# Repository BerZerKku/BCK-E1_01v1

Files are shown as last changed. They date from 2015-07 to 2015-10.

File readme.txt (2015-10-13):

БЦК-Е1

Код ПП: 3.140.003
Код ПП в сборе: 2.140.012

Плата не жизнеспособна! Первый вывод микросхемы 82V2084 находится не по той стороне!
Отверстия под  RJ45 меньше необходимых !

Стэк:
18мкм  TOP 
0.36мм e=4.5
35мкм  GND
0.71мм e=4.5
35мкм  PWR
0.36мм e=4.5
18мкм  BOTTOM
Волновое сопротивление для одиночного проводника: 0.50 мм = 60 Ом (Оркад).
Волновое сопротивление для одиночного проводника: 0.25 мм = 78 Ом (Оркад).
Диф. волновое сопротивление двух проводников: 0.25 мм через 0.25 мм = 120 Ом (Оркад).

!!! Возможно нужны резисторы на шины.

Вопросы:
1. Что делать со сбросом MCU? Завести в альтеру или просто подтянуть к питанию?
2. Не нашел примеров схем с 82V2084, надо ли ставить фильтры по питанию? или достаточно конденсаторов?
3. Разобраться с необходимыми подтяжками сигналов.

Замечания:

MISC
1. На двунаправленной шине данных, подключенной к STM стоит только 5-и вольтовая логика, т.к. все входы МК совместимы с 5В.
2. На входные сигналы идущие в ПЛИС стоит 3-х вольтовая логика тоже совместимую с 5В.
3. На BUSR3 вместо диода стоит транзистор.
4. Разъемы для RJ-45 выбраны 20см с контактом на корпус.

MCU
1. Поставлен резистор 220 Ом последовательно с кварцем. В части тестовых плат он есть, на части нет.
2. BOOT0 = "0", загрузка из FLASH. BOOT1 - не используется.
3. PDR_ON = VDD, внутренняя схема сброса включена.
4. VCAP_1(2) - 2.2 мкФ.
5. 4-е конденсатора 0805 2.2 мкФ, вместо двух по 4.7 мкФ. 12-ть конденсаторов 0805 по 0.1 мкФ. Количество и размеры конденсаторов может измениться по ходу разводки. 
6. VBAT, VUSB напрямую к VDD. 
7. VDDA через бусину к VDD, а так же конденсаторы 1.0 и 0.1 мкФ.
8. VREF+ напрямую к VDDA, а также конденсаторы 1.0 и 0.1 мкФ).
9. Кварц подключен через 220 Ом. На части демоплат этот резистор есть, на части нет. Размер 0805, на демо - скорее всего 0603.
10. Выводы JTAG имеют внутреннюю подтяжку и нет необходимости использовать внешние элементы.

E1
1. Последовательно на выходы/выходы E1 стоят нулевые резисторы 0805, чтобы при необходимости заменить на другой номинал.
2. JTAG TRST подключен к земле "For normal signal processing, this pin should be connected to ground".
3. REF подключен к земле через 0805 3кОм 1%. 
4. IC_7, IC_39 посажены на землю, IC_42 в воздухе.

CPLD
1. Ножки пока назначены для вида. Перестановка будет при разводке.
2. Добавил сигнал #DEV_CLR идущий с одной из ножек CPLD на ножку DEV_CLRn как на БЦК.

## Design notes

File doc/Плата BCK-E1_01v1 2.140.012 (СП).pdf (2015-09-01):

№ | Наименование | Корпус | Кол. | Поз. | Примечание
| | | | | 2.140.012

0

Изм | Лист | № докум. | Подп. | Дата
Разраб. | Щеблыкин М.В | | 01.09.15 | Плата BCK-E1_01v1 Спецификация | Лит. «Прософт-Системы» Н.контр. | Лист | Листов
Провер. | Сагалов Д.С. | | 01.09.15 | | | 1 | 4

### ООО

Назаренко А.Н. | 01.09.15
Утв. | Чирков А.Г.
1 | Сборочный чертеж
| 2.140.012 rev.0 | 1

ДЕТАЛИ
3 | Плата печатная
| 3.140.03 BCK-E1_01v1 | 1

ПРОЧИЕ ИЗДЕЛИЯ

5

Кварцевый резонатор KX-3H
16.3840MHz HC-49/S Geyer | LEAD | 1 | ZQ1

Конденсаторы

9 | 0805 NP0 50V 22pF 5% | 0805 | 2 | C66,C67
11 | 0805 X7R 50V 0.1uF 10% | 0805 | 47 | C8-C19,C21-C23,C26-C29,C32-C35, C37,C39-C43,C45-C58,C61,C68-C70
13 | 0805 X7R 50V 1uF 10% | 0805 | 6 | C2,C3,C20,C36,C59,C62
15 | 0805 X7R 50V 2.2uF 10% | 0805 | 7 | C4-C7,C38,C64,C65
17 | 0805 X7R 10V 10uF 10% | 0805 | 1 | C44
19 | 1812 X7R 3000V 1000pF 10% | 1812 | 2 | C60,C63
21 | тант. 10V 68uF 10% B | B | 5 | C1,C24,C25,C30,C31

Микросхемы

25 | 82V2084PF 128TQFP IDT | TQFP128 | 1 | DD6
27 | ADP3339AKCZ-3.3 SOT223-3 AD | SOT223 | 1 | DA1

2.140.012

Лист

Изм | Лист | № докум. | Подп. | Дата
29 | EPM1270T144C4N TQFP144 Altera | TQFP144 | 1 | DD5
31 | SN74ACT245DW SOIC20 TI | SOIC20 | 2 | DD1,DD2
33 | SN74LVC573ADW SOIC20 TI | SOIC20 | 2 | DD3,DD4
35 | SRDA05-4BTG SOIC8 LittleFuse | SOIC8 | 3 | VD24-VD26
37 | STM32F446ZET6 LQFP144 STM | LQFP144 | 1 | DD7
41 | Предохранитель 04611.25ER
Littelfuse | SMT-2 | 8 | F1-F8

Разъемы

45

1-5406299-1 на плату угловой Ethernet RJ45 R/A 8P T/H SLD
Tyco
10 | 2 | X3,X4
47 | DIN 3x32 96MR | DIN96 | 2 | X1,X2
49 | IDC-10M | IDC10 | 1 | X7
51 | PBD-08 | 8 | 1 | X9
53 | PLS-2 | 2 | 2 | X5,X6
55 | PLS-8 | 8 | 2 | X8,X10

Резисторы

59 | 0805 0 | 0805 | 8 | R12-R15,R24-R27
61 | 0805 60.4 1% | 0805 | 4 | R10,R11,R22,R23
63 | 0805 75 5% | 0805 | 12 | R16-R21,R28-R33
65 | 0805 100 5% | 0805 | 1 | R7
67 | 0805 220 5% | 0805 | 1 | R36
69 | 0805 510 5% | 0805 | 1 | R37
71 | 0805 1K 5% | 0805 | 6 | R2-R4,R6,R8,R9
73 | 0805 2.2K 5% | 0805 | 2 | R1,R5

75 | 0805 3.01K 1% | 0805 | 1 | R34
77 | 0805 5.1K 5% | 0805 | 1 | R35
79 | сборка 1206x4 100 5% | SMT-8 | 8 | RN1-RN8
81 | сборка 1206x4 1K 5% | SMT-8 | 1 | RN22
83 | сборка 1206x4 10K 5% | SMT-8 | 15 | RN9-RN21,RN23,RN24

Светодиоды

87 | FYL-5013PURD1C-60 красный
625нм D5мм 2200мКд Foryard | LEAD-2 | 2 | VD1,VD5 | красный
89 | KP-1608SGC Kingbright (level:3) | 0603 | 1 | VD7 | зеленый
91 | L-53GD | LEAD-2 | 3 | VD2,VD3,VD6 | зеленый
93 | L-53SYT Kingbright | LEAD-2 | 1 | VD4 | желтый

Тиристоры

97 | P0080SAMCLRP Littelfuse | DO-214AA | 4 | VD11,VD12,VD19,VD20
99 | P0300SCMCLRP Littelfuse | DO-214AA | 4 | VD8,VD15,VD16,VD23
101 | P1800SCMCLRP Littelfuse | DO-214AA | 8

VD9,VD10,VD13,VD14,VD17,VD18, VD21,VD22

105 | Транзистор IRLML2803 SOT23 IR | SOT23-3 | 1 | VT1
109 | Трансформатор T1094NL Pulse | SOIC16 | 2 | TR1,TR2
113 | Фильтр PE-65857NL Pulse | SOIC8 | 2 | L1,L2
117 | Фильтр ферритовый BLM18HG471SN1
470Ом 200мА 0603 Murata | 0603 | 3 | FB1-FB3

Лист регистрции изменений СП
№ Изм. | № замененных (измененных) страниц | Дата ревизии | Краткое содержание и причина внесения изменений | Примечание
0 | вновь | 01.09.15

Исполнения:

Лист регистрции изменений СБ
№ Изм. | № замененных (измененных) страниц | Дата ревизии | Краткое содержание и причина внесения изменений | Примечание
0 | вновь | 01.09.15

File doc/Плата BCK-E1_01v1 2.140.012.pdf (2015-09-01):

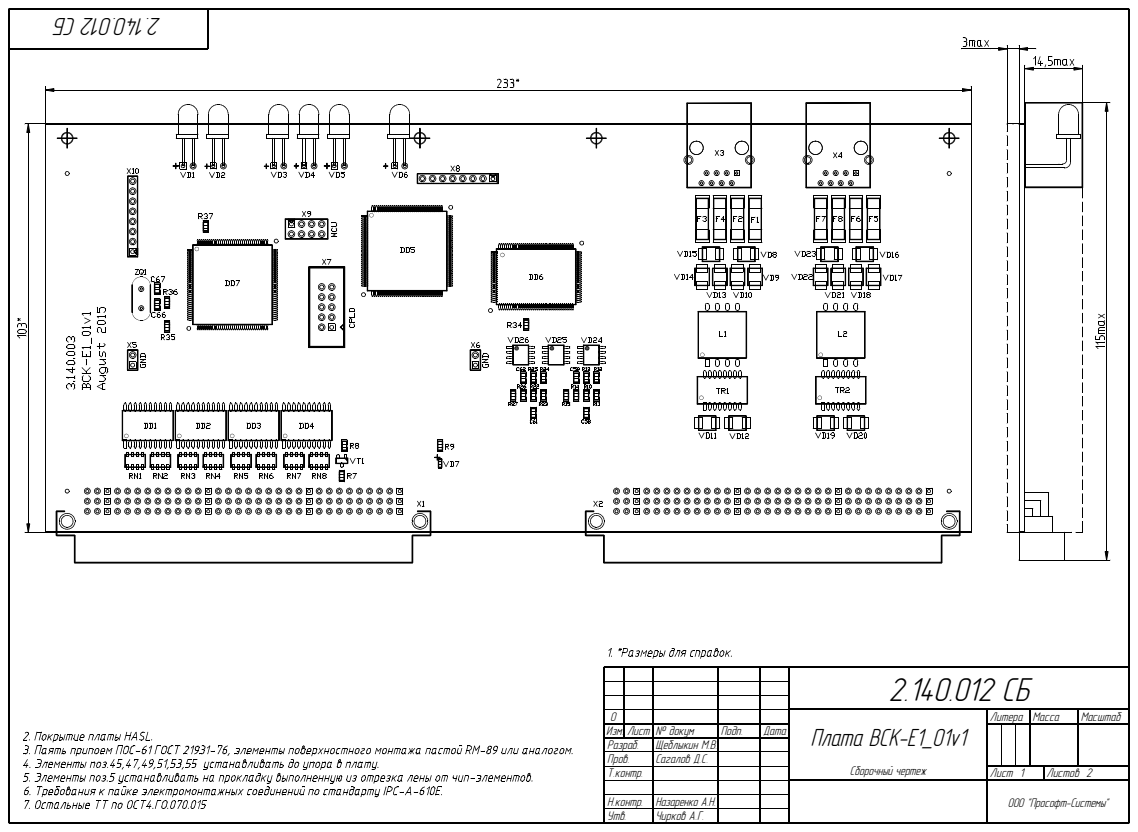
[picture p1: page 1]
Ëèñòîâ 2; Ìàññà; Ìàñøòàá; Ïîäï.; Äàòà; Óòâ.; Í.êîíòð.; Ò.êîíòð.; Ïðîâ.; Ðàçðàá.; Èçì. Ëèñò; ×èðêîâ À.Ã.; Íàçàðåíêî À.Í.; Ñàãàëîâ Ä.Ñ.; Ùåáëûêèí Ì.Â.; № äîêóì; Ëèñò 1; Ëèòåðà; Ïëàòà BCK-E1_01v1

Ñáîðî÷íûé ÷åðòåæ

ÎÎÎ "Ïðîñîôò-Ñèñòåìû"

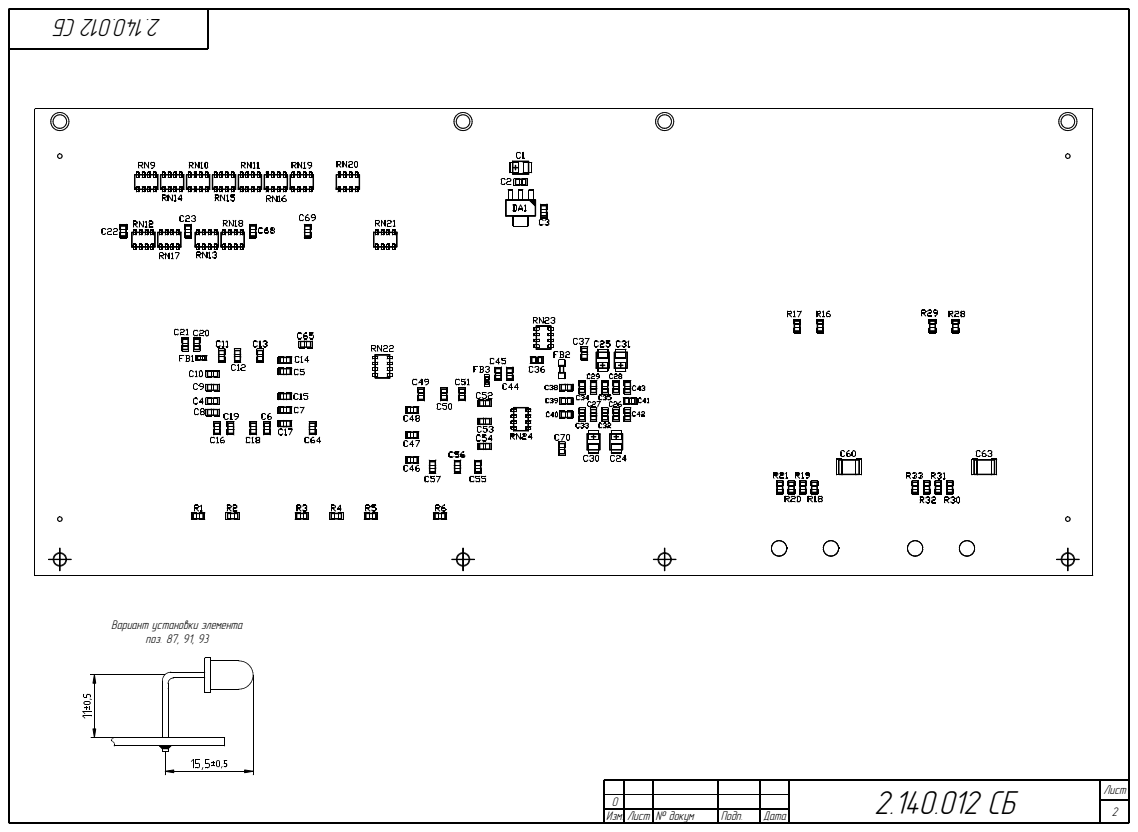
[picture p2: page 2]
Ëèñò; Èçì. Ëèñò № äîêóì; Ïîäï.; Äàòà; ïîç. 87, 91, 93

Âàðèàíò óñòàíîâêè ýëåìåíòà

№ | Наименование | Корпус | Кол. | Поз. | Примечание
| | | | | 2.140.012

0

Изм | Лист | № докум. | Подп. | Дата
Разраб. | Щеблыкин М.В | | 01.09.15 | Плата BCK-E1_01v1 Спецификация | Лит. «Прософт-Системы» Н.контр. | Лист | Листов
Провер. | Сагалов Д.С. | | 01.09.15 | | | 1 | 4

### ООО

Назаренко А.Н. | 01.09.15
Утв. | Чирков А.Г.
1 | Сборочный чертеж
| 2.140.012 rev.0 | 1

ДЕТАЛИ
3 | Плата печатная
| 3.140.03 BCK-E1_01v1 | 1

ПРОЧИЕ ИЗДЕЛИЯ

5

Кварцевый резонатор KX-3H
16.3840MHz HC-49/S Geyer | LEAD | 1 | ZQ1

Конденсаторы

9 | 0805 NP0 50V 22pF 5% | 0805 | 2 | C66,C67
11 | 0805 X7R 50V 0.1uF 10% | 0805 | 47 | C8-C19,C21-C23,C26-C29,C32-C35, C37,C39-C43,C45-C58,C61,C68-C70
13 | 0805 X7R 50V 1uF 10% | 0805 | 6 | C2,C3,C20,C36,C59,C62
15 | 0805 X7R 50V 2.2uF 10% | 0805 | 7 | C4-C7,C38,C64,C65
17 | 0805 X7R 10V 10uF 10% | 0805 | 1 | C44
19 | 1812 X7R 3000V 1000pF 10% | 1812 | 2 | C60,C63
21 | тант. 10V 68uF 10% B | B | 5 | C1,C24,C25,C30,C31

Микросхемы

25 | 82V2084PF 128TQFP IDT | TQFP128 | 1 | DD6
27 | ADP3339AKCZ-3.3 SOT223-3 AD | SOT223 | 1 | DA1

2.140.012

Лист

Изм | Лист | № докум. | Подп. | Дата
29 | EPM1270T144C4N TQFP144 Altera | TQFP144 | 1 | DD5
31 | SN74ACT245DW SOIC20 TI | SOIC20 | 2 | DD1,DD2
33 | SN74LVC573ADW SOIC20 TI | SOIC20 | 2 | DD3,DD4
35 | SRDA05-4BTG SOIC8 LittleFuse | SOIC8 | 3 | VD24-VD26
37 | STM32F446ZET6 LQFP144 STM | LQFP144 | 1 | DD7
41 | Предохранитель 04611.25ER
Littelfuse | SMT-2 | 8 | F1-F8

Разъемы

45

1-5406299-1 на плату угловой Ethernet RJ45 R/A 8P T/H SLD
Tyco
10 | 2 | X3,X4
47 | DIN 3x32 96MR | DIN96 | 2 | X1,X2
49 | IDC-10M | IDC10 | 1 | X7
51 | PBD-08 | 8 | 1 | X9
53 | PLS-2 | 2 | 2 | X5,X6
55 | PLS-8 | 8 | 2 | X8,X10

Резисторы

59 | 0805 0 | 0805 | 8 | R12-R15,R24-R27
61 | 0805 60.4 1% | 0805 | 4 | R10,R11,R22,R23
63 | 0805 75 5% | 0805 | 12 | R16-R21,R28-R33
65 | 0805 100 5% | 0805 | 1 | R7
67 | 0805 220 5% | 0805 | 1 | R36
69 | 0805 510 5% | 0805 | 1 | R37
71 | 0805 1K 5% | 0805 | 6 | R2-R4,R6,R8,R9
73 | 0805 2.2K 5% | 0805 | 2 | R1,R5

75 | 0805 3.01K 1% | 0805 | 1 | R34
77 | 0805 5.1K 5% | 0805 | 1 | R35
79 | сборка 1206x4 100 5% | SMT-8 | 8 | RN1-RN8
81 | сборка 1206x4 1K 5% | SMT-8 | 1 | RN22
83 | сборка 1206x4 10K 5% | SMT-8 | 15 | RN9-RN21,RN23,RN24

Светодиоды

87 | FYL-5013PURD1C-60 красный
625нм D5мм 2200мКд Foryard | LEAD-2 | 2 | VD1,VD5 | красный
89 | KP-1608SGC Kingbright (level:3) | 0603 | 1 | VD7 | зеленый
91 | L-53GD | LEAD-2 | 3 | VD2,VD3,VD6 | зеленый
93 | L-53SYT Kingbright | LEAD-2 | 1 | VD4 | желтый

Тиристоры

97 | P0080SAMCLRP Littelfuse | DO-214AA | 4 | VD11,VD12,VD19,VD20
99 | P0300SCMCLRP Littelfuse | DO-214AA | 4 | VD8,VD15,VD16,VD23
101 | P1800SCMCLRP Littelfuse | DO-214AA | 8

VD9,VD10,VD13,VD14,VD17,VD18, VD21,VD22

105 | Транзистор IRLML2803 SOT23 IR | SOT23-3 | 1 | VT1
109 | Трансформатор T1094NL Pulse | SOIC16 | 2 | TR1,TR2
113 | Фильтр PE-65857NL Pulse | SOIC8 | 2 | L1,L2
117 | Фильтр ферритовый BLM18HG471SN1
470Ом 200мА 0603 Murata | 0603 | 3 | FB1-FB3

Лист регистрции изменений СП
№ Изм. | № замененных (измененных) страниц | Дата ревизии | Краткое содержание и причина внесения изменений | Примечание
0 | вновь | 01.09.15

Исполнения:

Лист регистрции изменений СБ
№ Изм. | № замененных (измененных) страниц | Дата ревизии | Краткое содержание и причина внесения изменений | Примечание
0 | вновь | 01.09.15

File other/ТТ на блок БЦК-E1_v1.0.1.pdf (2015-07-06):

Технические Требования на блок БЦК-E1

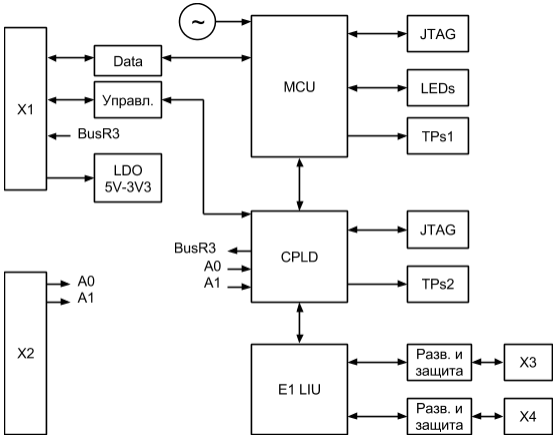
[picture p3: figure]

Общее описание
1. Блоксхема БЦК-E1 представлена на рисунке выше
2. При разработке схемотехники блока БЦК-E1 нужно ориентироваться на схемотехнику блока БЦКО_v2.3 (в той части, которая не описана здесь и которая является общей для обоих блоков)
4. Физические размеры см. БЦКО_v2.3
3. Основное напряжение питания блока 3.3В

Элементная база
1. MCU STM32F446ZET6
2. E1 LIU (Line Interface Unit) IDT82V2084
3. CPLD ALTERA EPM1270T144C4N (в перспективе замены в серийном изделии на младшую модель ALTERA EPM240T100C5N, когда будут определены задействованные ресурсы CPLD)
4. Остальное из схемотехники блока БЦКО_v2.3

Системная шина
1. За основу схемотехники взять реализацию буфера системной шины блока БЦКО_v2.3
2. Разрядность шины данных 16 бит (завести в MCU)
3. Разрядность шины адреса 4 бита (завести в CPLD)
4. #CS0...#CS4, #RD, #WR, BL, #RES, BUSR3, A0, A1 в CPLD
5. BUSR3 подключать к разъему X1 через диод (монтажное ИЛИ), как на БЦКО_v2.3
6. Сигналы управления (OE, DIR) в CPLD

MCU
1. напряжение питания 3.3В
2. Кварцевый резонатор 16 МГц
3. JTAG разъем: на базе PBD-8 со следующим расположением контактов
1 | JNTRST | 2 | JTDO
3 | JTDI | 4 | 3V3
5 | JTCK | 6 | GND
7 | JTMS | 8 | N.C.
4. SAI1 (SAI1_FS_A/B, SAI1_MCLK_A/B, SAI1_SCK_A/B, SAI1_SD_A/B) в CPLD
5. SAI2 (SAI2_FS_A/B, SAI2_MCLK_A/B, SAI2_SCK_A/B, SAI2_SD_A/B) в CPLD
6. SPI1 (SPI1_MOSI, SPI1_MISO, SPI1_SCK, SPI1_NSS) в CPLD
7. RCC (RCC_MC0_1 (PA8), RCC_MC0_2 (PC9)) в CPLD
8. FMC:
FMC_D15...FMC_D0 на буферы шины данных системной шины FMC_A3...FMC_A0 в CPLD
FMC_NE1, FMC_NL, FMC_NOE, FMC_NWAIT, FMC_NWE в CPLD
9. В качестве резерва часть неиспользуемых портов ввода/вывода завести в CPLD (не менее 8)
10. 8 неиспользуемых портов ввода/вывода использовать в качестве тестовых точек. Вывести их на разъем PLS-8
11. Вывести 6 светодиодов индикации. Схемотехника и положение (его можно скорректировать, т.к. оно не совпадает с положением отверстий на панели) как на блоке БЦКО_v2.3

Для уточнения расположения выводов микросхемы можно использовать программу STM32CubeMX со следующими настройками:
Тип микросхемы: STM32F446ZETx
FMC:
Nor Flash/PSRAM/SRAM/ROM 1
Chip Select: NE1

Memory type: NOR Flash
Address: 4 bits
Data: 16 bits
Clock: Disable
Address valid: check
Wait: Asynchronous

RCC:
High Speed Clock (HSE): Crystal/Ceramic Resonator Low Speed Clock (LSE): Disable
Master Clock Output 1: check
Master Clock Output 2: check

SAI1:
SAI A:
Mode: Master with Master Clock Out I2S/PCM Protocol: uncheck
SAI B:
Mode: Master with Master Clock Out I2S/PCM Protocol: uncheck

SAI2:
SAI A:
Mode: Master with Master Clock Out I2S/PCM Protocol: uncheck
SAI B:
Mode: Master with Master Clock Out I2S/PCM Protocol: uncheck

SPI1:
Mode: Full-Duplex Master
Hardware NSS Signal: check

E1 Driver
1. напряжение питания 3.3В
2. Необходимо использовать 2 любых порта (из 4-х), наиболее удобные для трассировки
3. Сигналы этих портов (LOSn, RCLKn, RDn/RDPn, CVn/RDNn, TCLKn, TDn/TDPn, TDNn) должны быть заведены в CPLD
4. ~CS, SCLK, SDI, SDO (последовательный порт управления) в CPLD
5. ~INT, ~RST, THZ, SCLKE, MCLK в CPLD
6. P/~S “0”
7. MCLKS “0”

Требования к портам E1
1. Количество портов 2 шт
2. Типы разъемов RJ45
3. Распиновка разъемов стандартная E1
4. Расположение разъемов нижняя часть блока
5. Волновое сопротивление линии 120 Ом
6. Схемы защиты от помех, согласование линии и гальваническая развязка в соответствии с документацией на IDT82V2048

CPLD
1. напряжение питания 3.3В
2. JTAG стандартный ALTERA JTAG, IDC10
3. 8 неиспользуемых портов ввода/вывода использовать в качестве тестовых точек. Вывести их на разъем PLS-8

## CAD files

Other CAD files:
doc/Плата BCK-E1_01v1 2.140.012 (СБ).dwg

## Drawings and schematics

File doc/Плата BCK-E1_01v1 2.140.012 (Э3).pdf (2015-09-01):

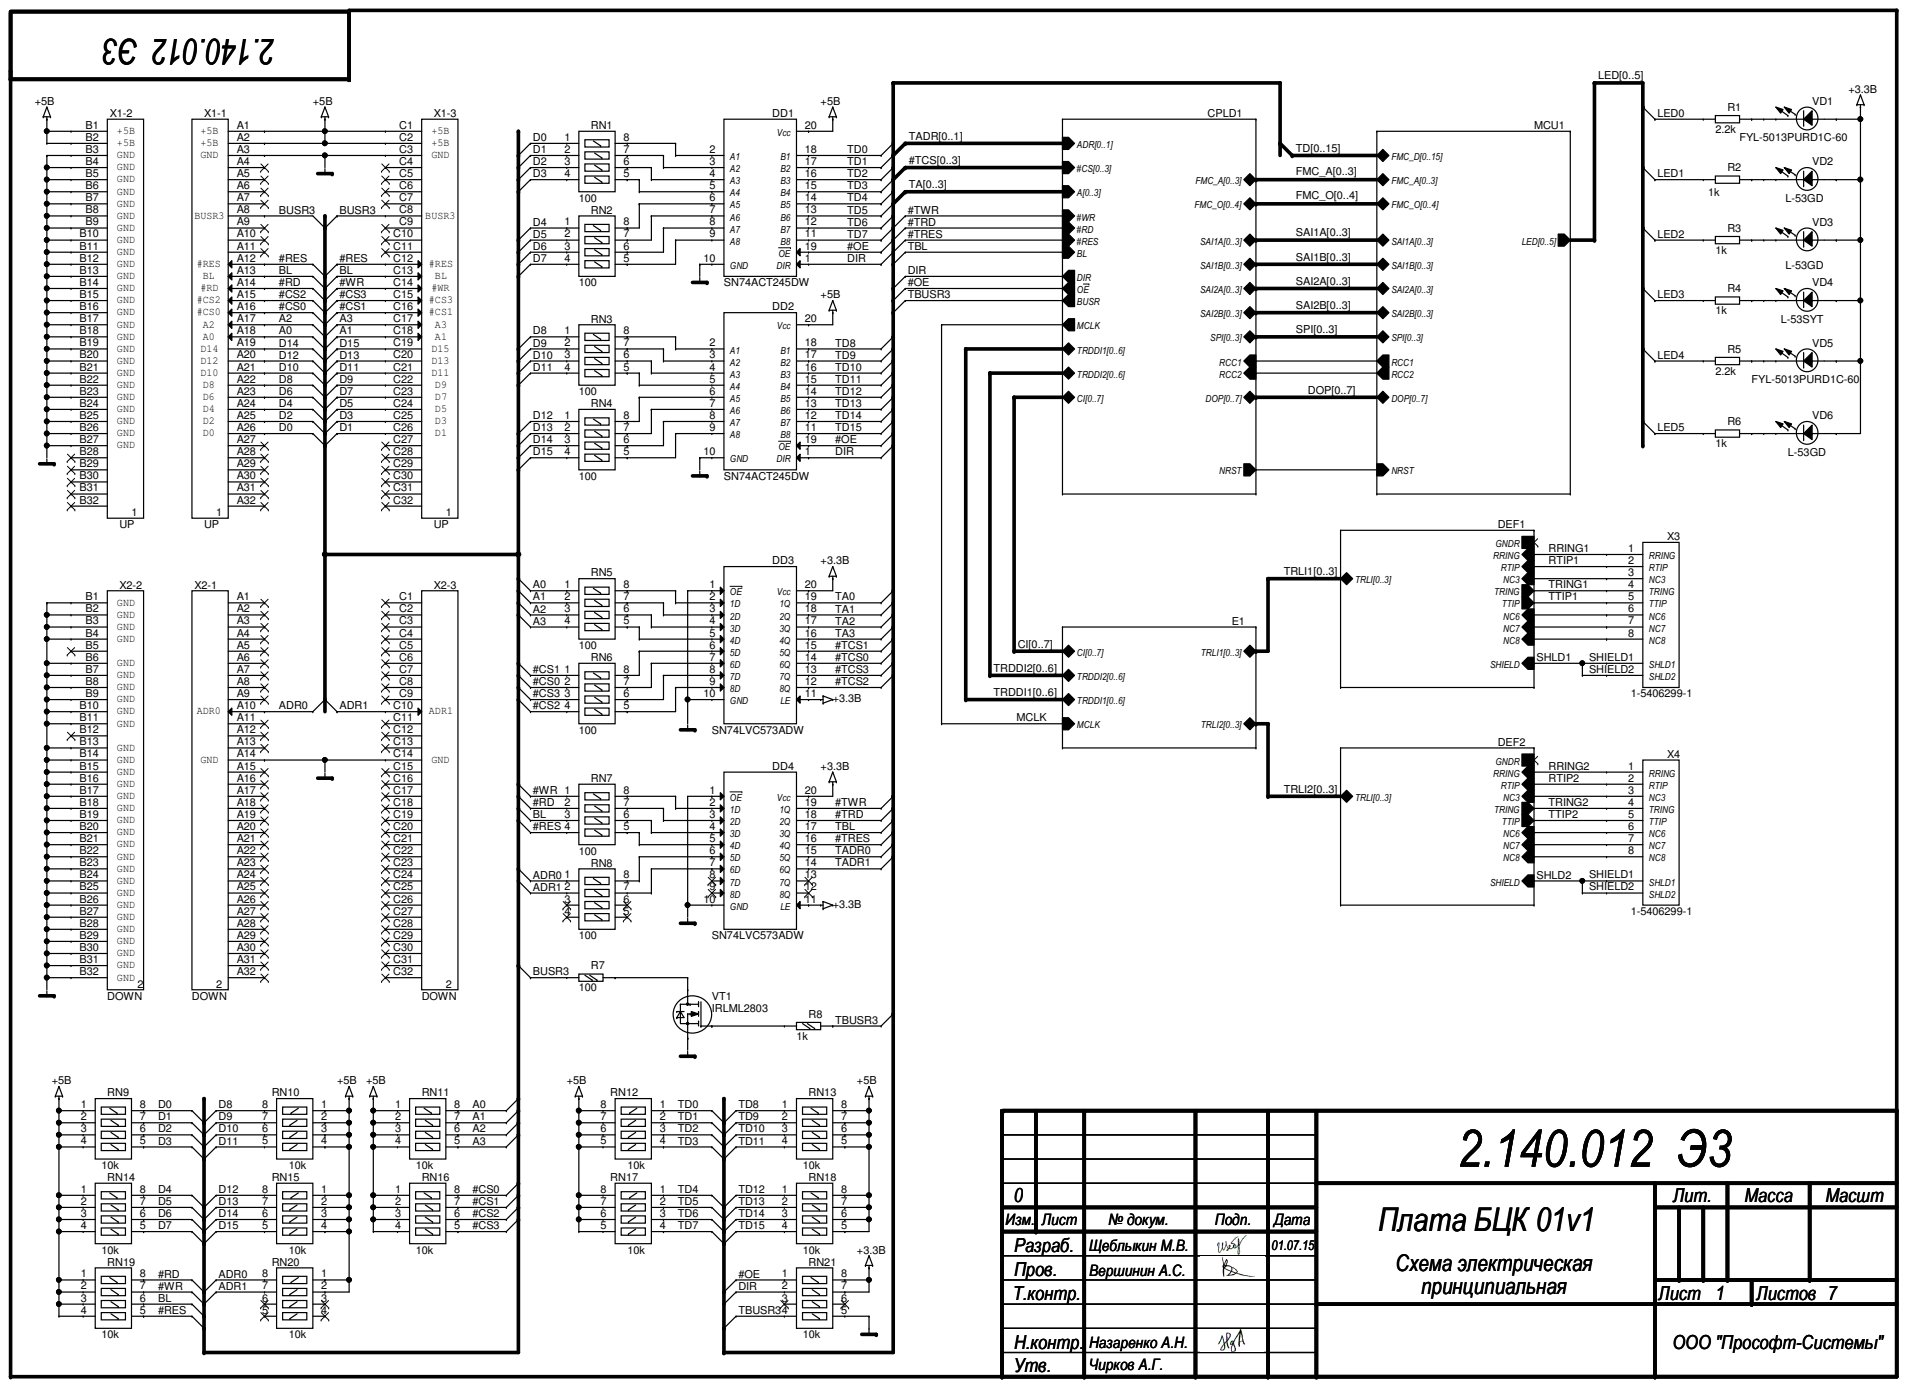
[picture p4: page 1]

Н.контр. Н.контр. Н.контр. | Назаренко А.Н. Назаренко А.Н. Назаренко А.Н.
Утв. Утв. Утв. | Чирков А.Г. Чирков А.Г. Чирков А.Г.

ООО "Прософт-Системы" ООО "Прософт-Системы" ООО "Прософт-Системы"

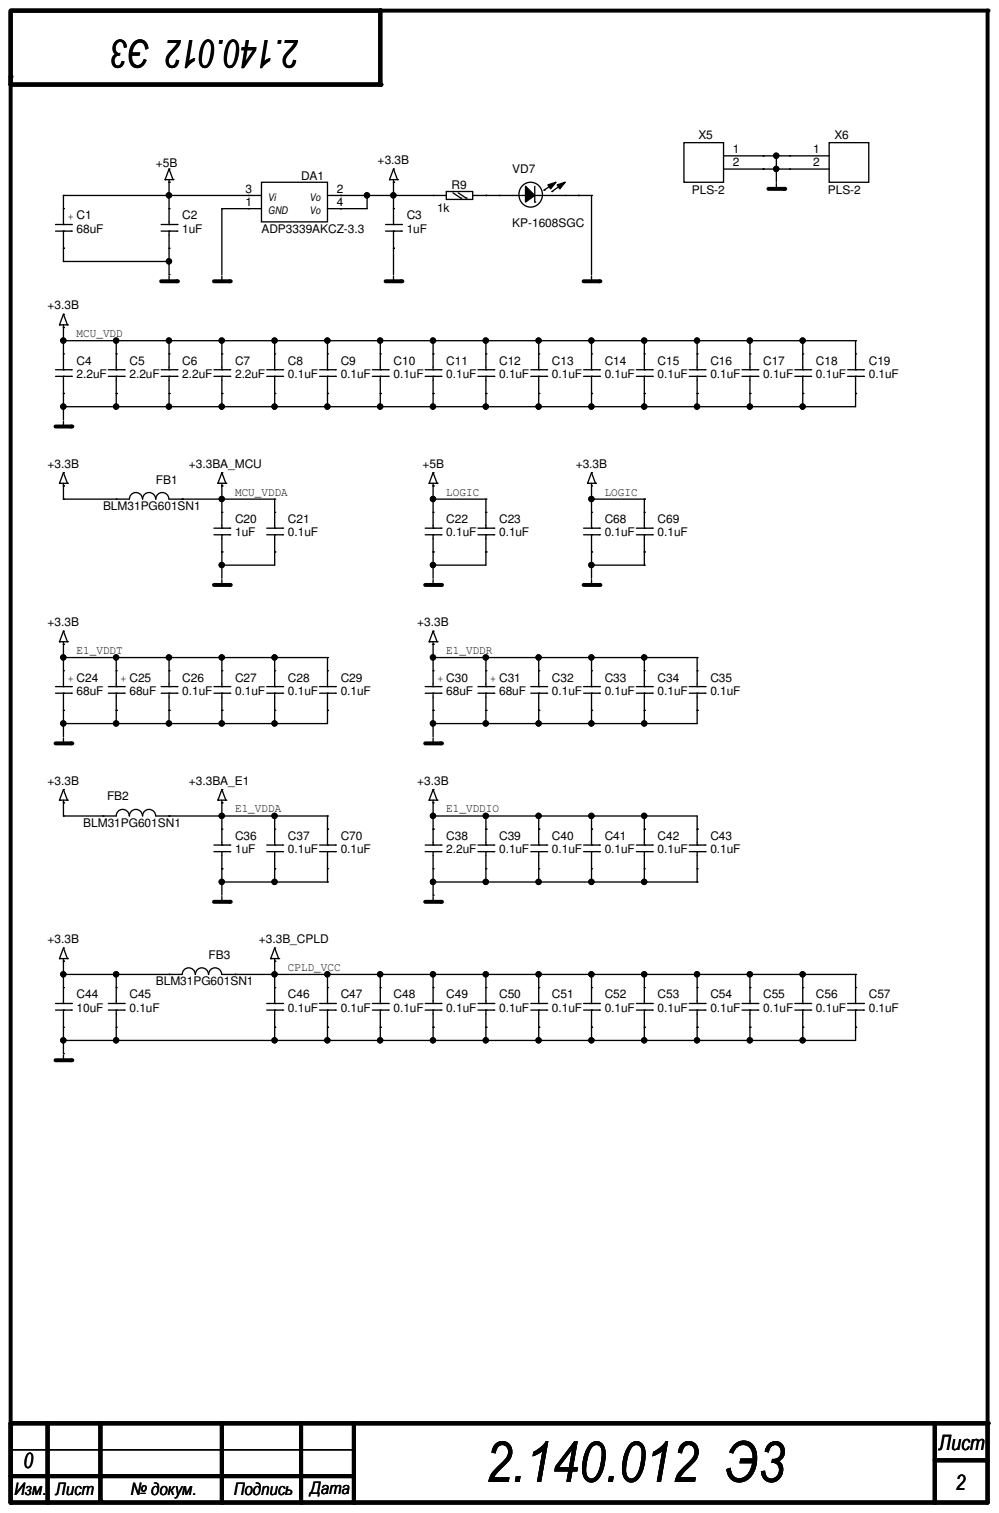
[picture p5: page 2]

Лист 2.140.012 Э3 Лист 2.140.012 Э3 Лист 2.140.012 Э3 2 2 2

Изм. | Лист | № докум. | Подпись | Дата

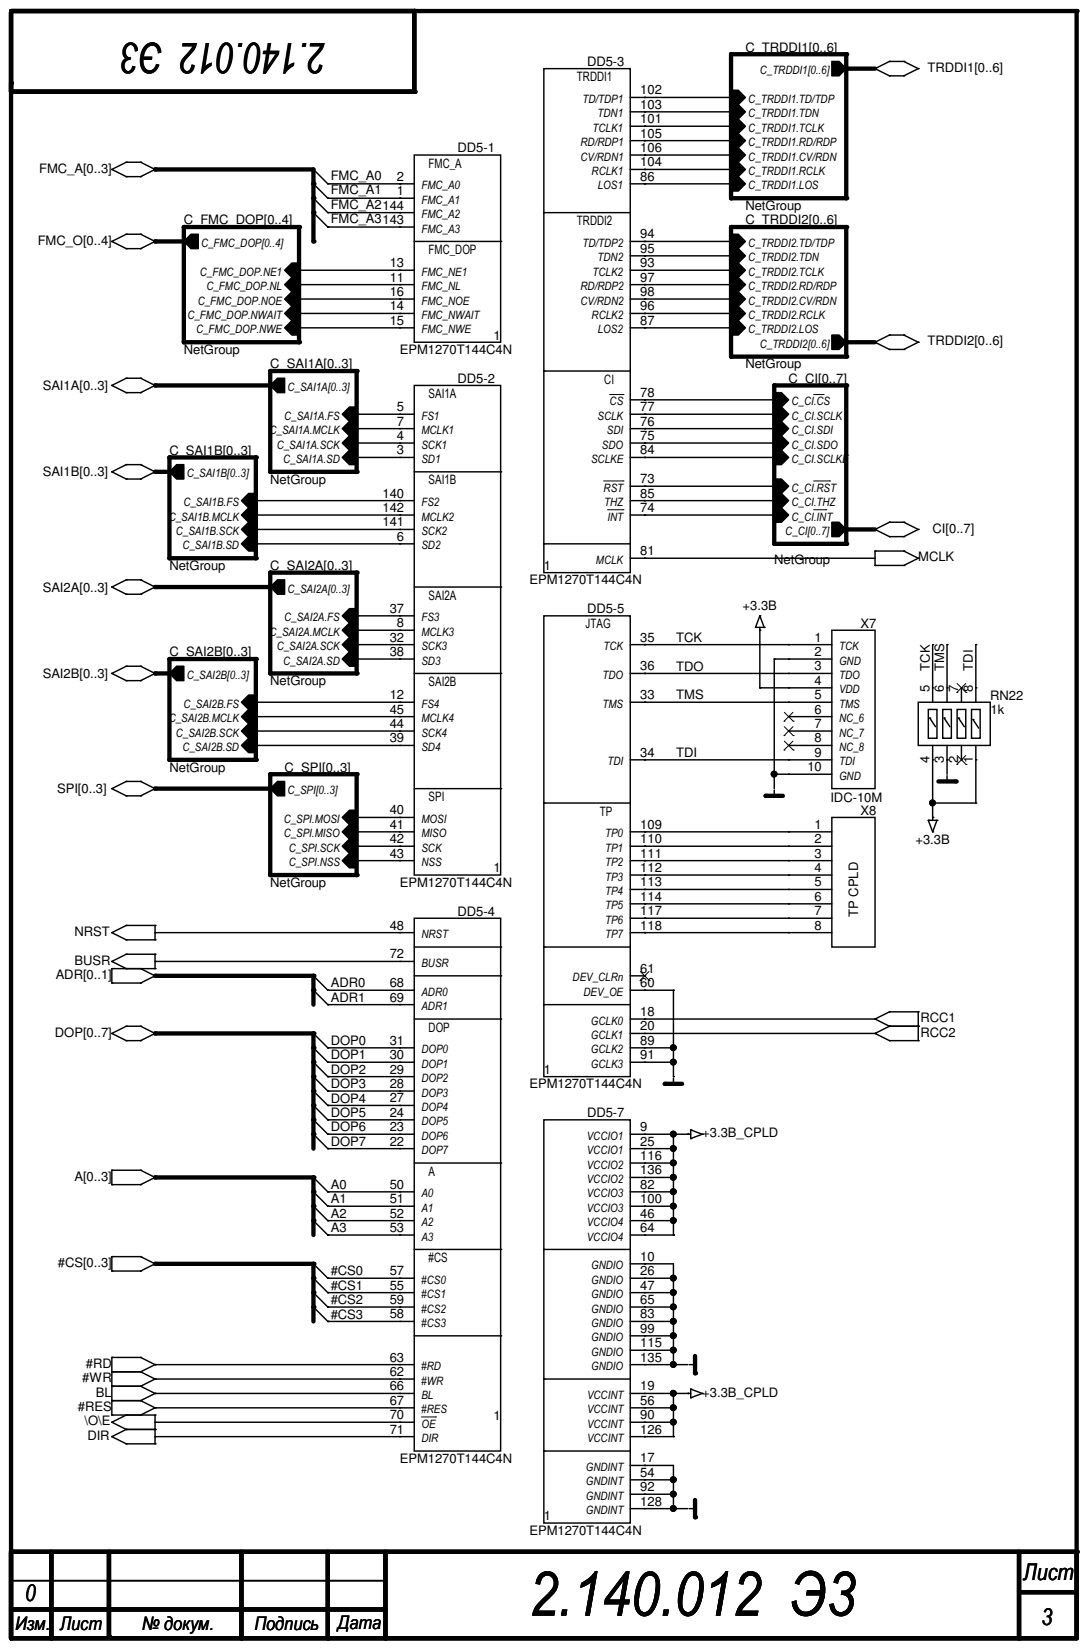
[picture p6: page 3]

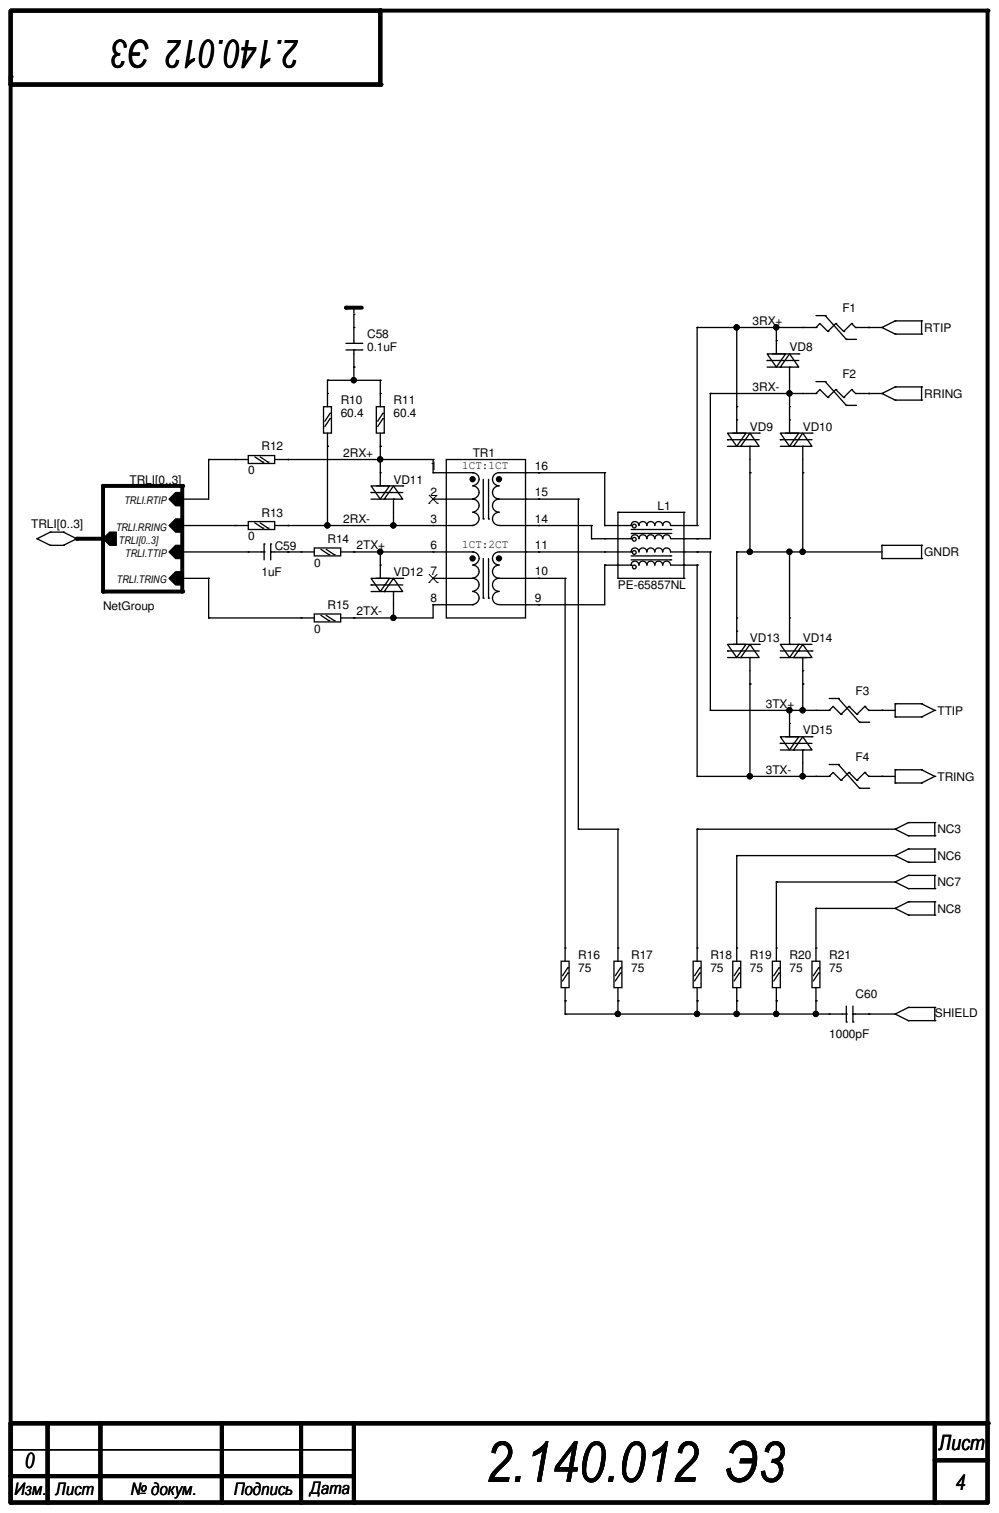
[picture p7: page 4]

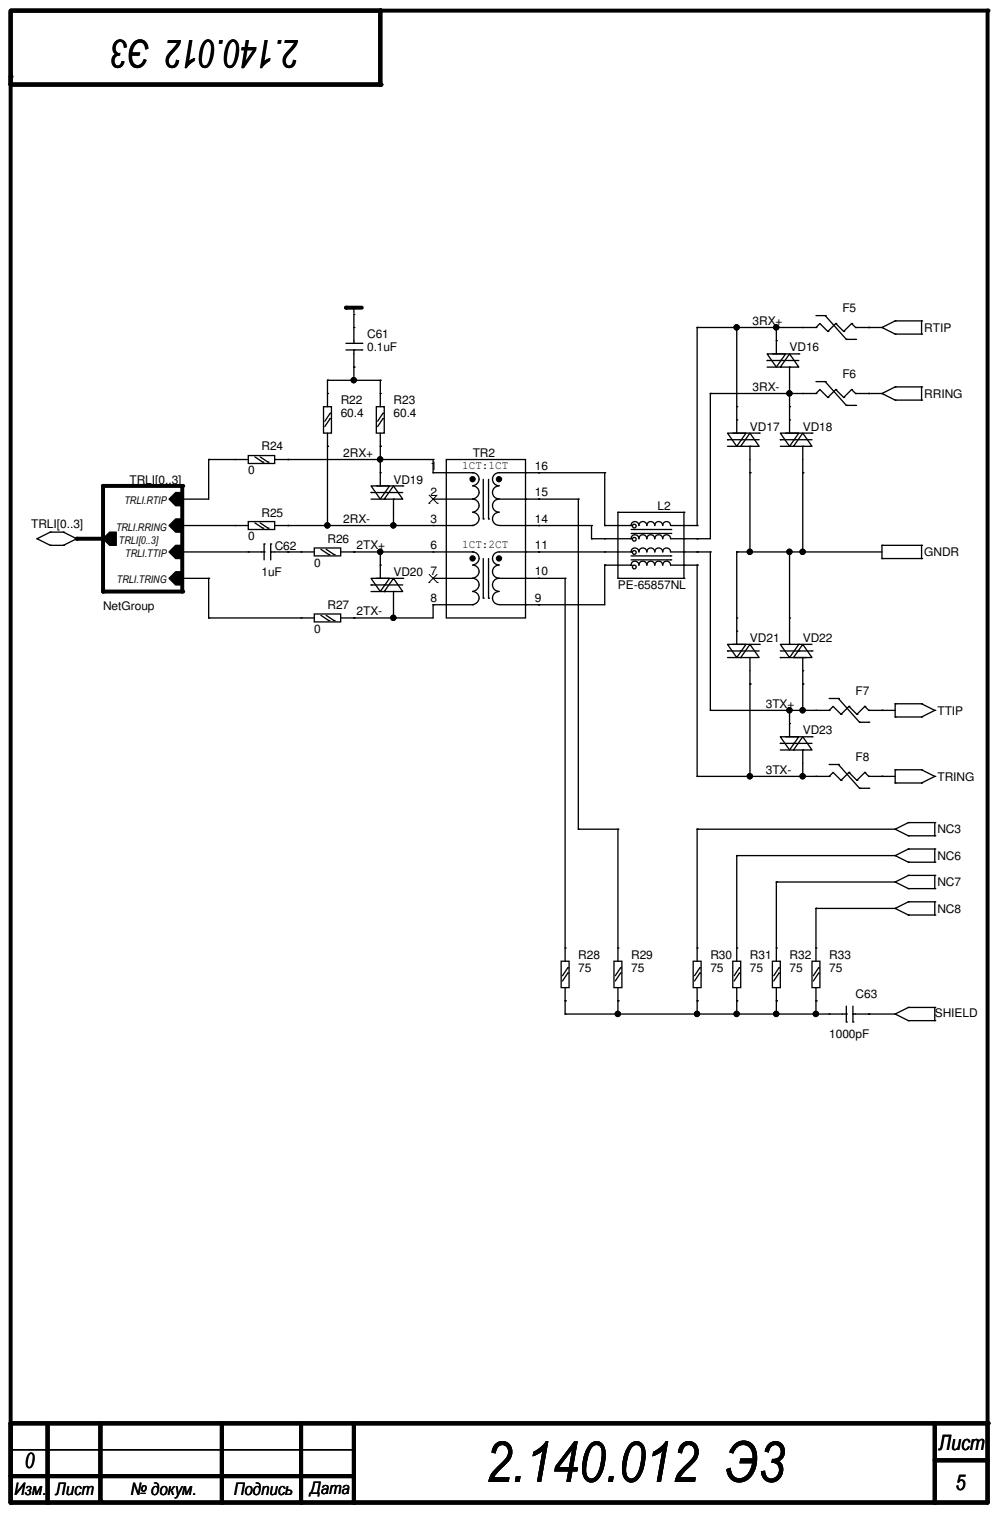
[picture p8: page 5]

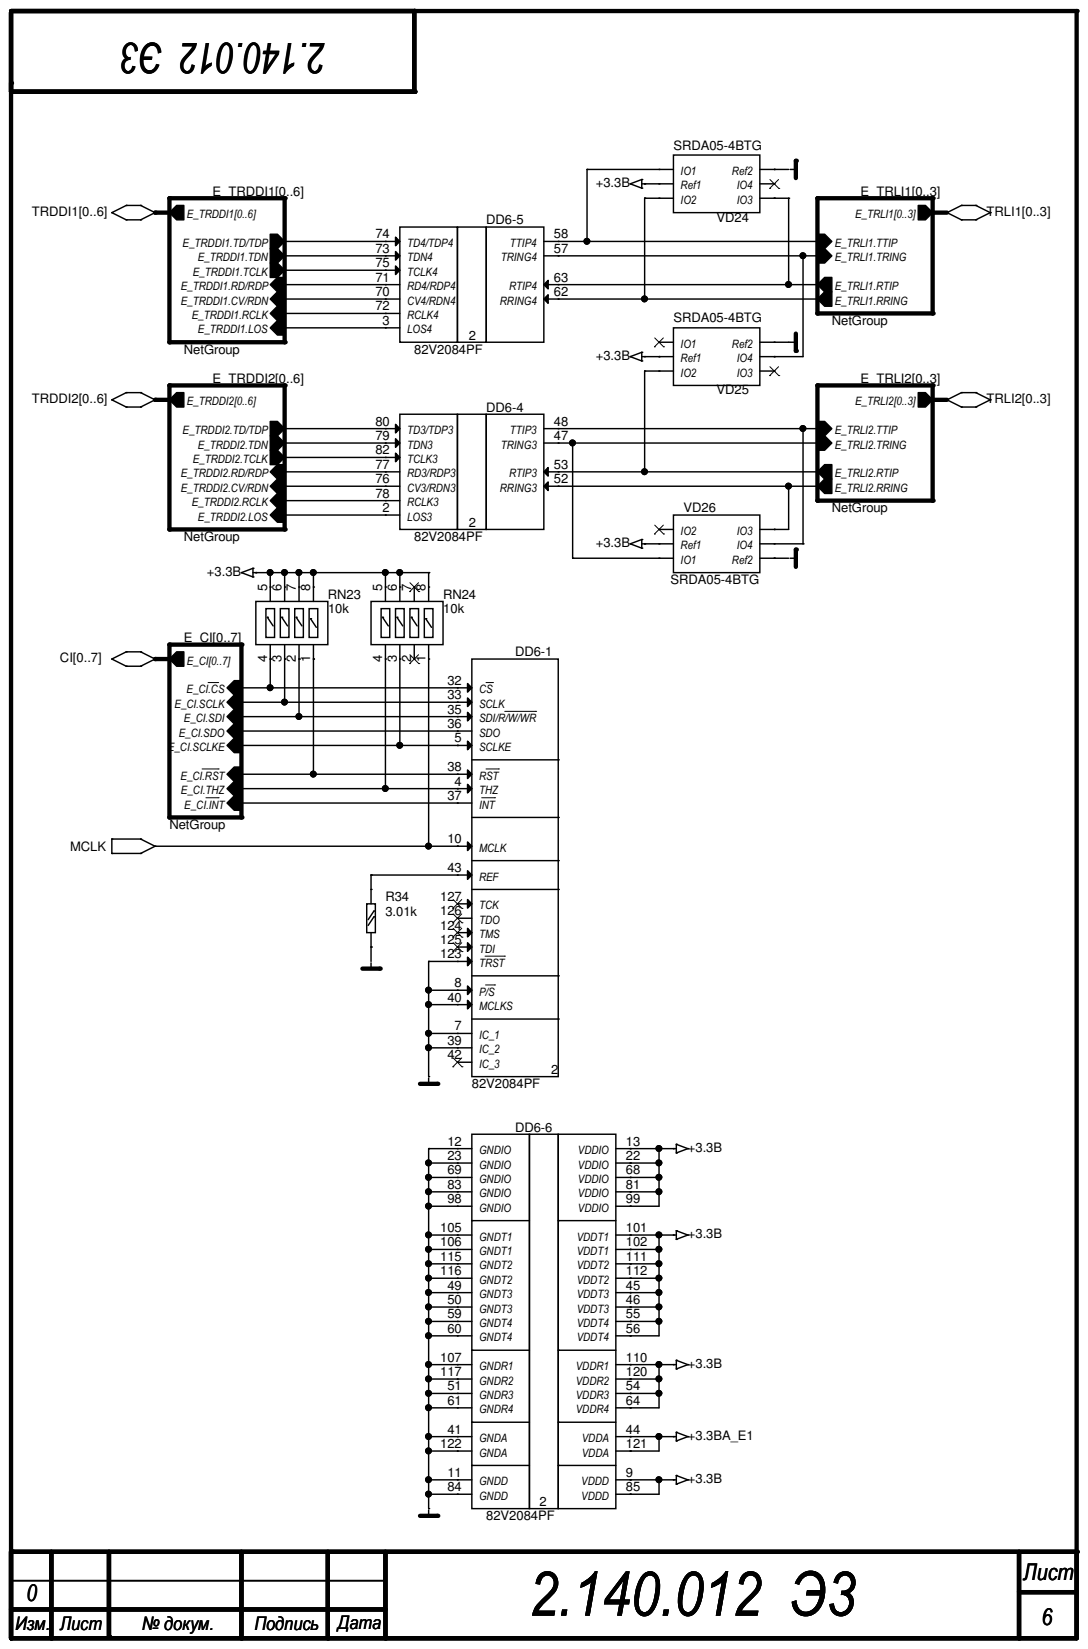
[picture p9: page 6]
TRDDI1[0..6]; TRDDI2[0..6]; TRLI1[0..3]; TRLI2[0..3]; MCLK; Лист 2.140.012 Э3; NetGroup; E_CI.CS E_CI.SCLK E_CI.SDI E_CI.SDO; E_CI.INT; E_CI.RST E_CI.THZ; E_CI.SCLKE; SCLK; SCLKE; SDI/R/W/WR; RST; MCLKS; THZ; SDO; INT; TRST; TCK; TDO; TMS; TDI; REF; SRDA05-4BTG; Ref1; Ref2; E_TRLI1[0..3]; E_TRLI1.TTIP E_TRLI1.TRING; E_TRLI1.RTIP E_TRLI1.RRING; VDDA; 121 GNDA; GNDA; VDDIO; GNDIO; VDDR1; VDDR2; VDDR3; VDDR4; GNDR1; GNDR2; GNDR3; GNDR4; VDDD; 85 GNDD; GNDD; VDDT1; 102 VDDT1; VDDT2; 112 VDDT2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

# X10TP MCU

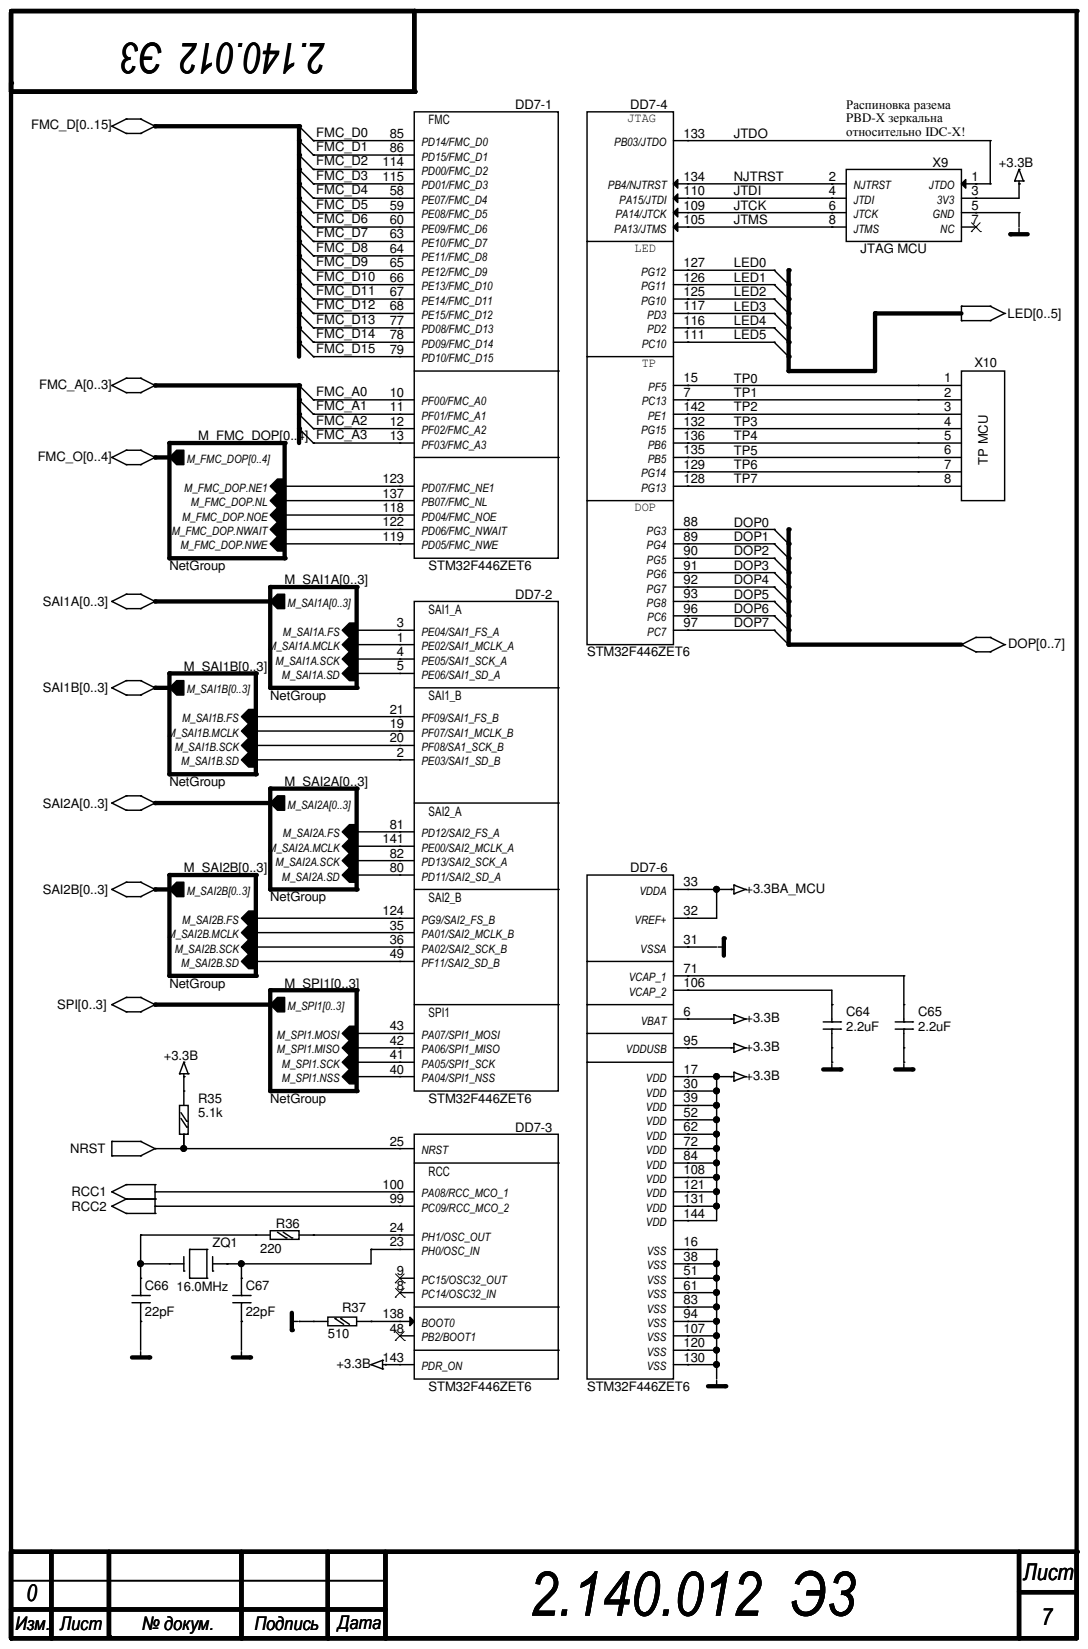
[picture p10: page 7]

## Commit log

2015-07-06 Начата работа над платой БЦК-Е1, по ТТ полученному от Сагалова Д. Нарисованы разъемы и входные цепи.
    [BCK-E1_01v1.DSN]
2015-07-07 Прорисованы общие связи. Начато редактирование символа МК.
    [BCK-E1_01v1.DSN]
2015-07-09 Частично прорисовано подключение МК.
    [BCK-E1_01v1.DSN]
2015-07-13 Нарисованы блоки Е1, DEF.
    [BCK-E1_01v1.DSN]
2015-07-15 Нарисована схема. Идет какая-то ошибка при нумерации элементов.
    [BCK-E1_01v1.DSN]
2015-07-15 Исправлены ошибки формирования списка цепей.
    [BCK-E1_01v1.DSN]
2015-07-15 Прорисовывается шаблон платы.
    [BCK-E1_01v1.DSN, BCK-E1_01v1.brd]
2015-07-16 На плате расставлены разъемы/отверстия/светодиоды.
    [BCK-E1_01v1.DSN, BCK-E1_01v1.brd]
2015-07-17 Добавлен стек слоев. Начата разводка.
    [BCK-E1_01v1.DSN, BCK-E1_01v1.brd]
2015-07-20 Начат поиск положения больших микросхем. Сделана прикидочная разводка входных цепей Е1.
    [BCK-E1_01v1.DSN, BCK-E1_01v1.brd]
2015-07-21 Перевернут МК.
    [BCK-E1_01v1.DSN, BCK-E1_01v1.brd]
2015-07-21 Начата разводка сигналов МК-ПЛИС с переносом необходимых.
    [BCK-E1_01v1.DSN, BCK-E1_01v1.brd]
2015-07-23 Закончена связка мк-плис. Начата равзодка цепей Е1-плис.
    [BCK-E1_01v1.DSN, BCK-E1_01v1.brd]
2015-07-24 Сделана разводка плис-е1 и входной шины данных.
    [BCK-E1_01v1.DSN]
2015-07-24 Сделана примерная разводка.
    [BCK-E1_01v1.DSN]
2015-07-24 Микросхема Е1 повернута на 90 градусов.
    [BCK-E1_01v1.DSN]
2015-07-28 Исправлено посадочное место для разъема Е1. Ведется разводка обвязки входов Е1.
    [BCK-E1_01v1.DSN]
2015-07-29 Разведена входная часть Е1.
    [BCK-E1_01v1.DSN]
2015-07-29 Разведены сигналы адреса платы.
    [BCK-E1_01v1.DSN]
2015-07-29 Начата разводка питания.
    [BCK-E1_01v1.DSN]
2015-07-30 Разведено питание МК.
2015-07-30 Расставлены подтяжки на ОЕ, DIR, BUSR3.
    [BCK-E1_01v1.DSN]
2015-07-30 Разведены конденсаторы для логики.
    [BCK-E1_01v1.DSN]
2015-07-30 Заменил ферритовую бусину на питании ПЛИС. Переделал ограничения для цепей PWR.
    [BCK-E1_01v1.DSN]
2015-07-31 Закончена предварительная разводка.
    [BCK-E1_01v1.DSN]
2015-07-31 Добавлены джампера земли и мелкие переделки.
2015-08-04 1. переименована цепь FMC_O -> FMC_CTRL; 2. переименована цепь DOP -> EXT; 3. ферриты на плис и мк заменены на 0603; 4. кварц изменен на выводной 16,384МГц; 5. GNDR на защите подключен к SHIELD, т.е.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
    [BCK-E1_01v1.DSN]
2015-08-04 Добавлены реперные точки для микросхемы Е1.
2015-08-04 Заменен феррит на питании Е1 и кварц МК. Сделано сглаживание разводки.
    [BCK-E1_01v1.DSN]
2015-08-04 Понижена точность чертежа с 4 до 3.
2015-08-04 Плата подготовлена к заказу.
    [BCK-E1_01v1.DSN]
2015-09-01 Добавлены файлы документации.
    [Плата BCK-E1_01v1 2.140.012 (СБ).dwg]
2015-09-28 Найдена ошибка на печатной плате: не устанавливается разъем RJ-45, отверстия меньшего диаметра.
2015-10-13 На плате обнаружена ошибка посадочного места под микросхему Е1, плата работать не будет.
2015-10-13 добавлен файл спецификации.
